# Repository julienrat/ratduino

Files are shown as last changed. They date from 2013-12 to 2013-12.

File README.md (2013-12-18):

Moduluino
======================================

Le moduluino est un arduino basé sur l'ATmega328P, il a l'avantage de concentrer le minimum pour fonctionner. son utilisation est destinée aux modules d'exposition,
le cout estimé est de 13 euros TTC chez seeedstudio.

Les fichiers de production ainsi que la BOM sont disposibles  et sont destinés à etre utilisés avec les services seeedstudio prototyping
http://www.seeedstudio.com/service/index.php?r=site/pcbService&type=pcba

Les fichiers sources sont compatibles EAGLE avec la librairie Open Parts Library  (http://www.seeedstudio.com/wiki/Open_parts_library)
Licence GNU GPL

PCB 

PCB

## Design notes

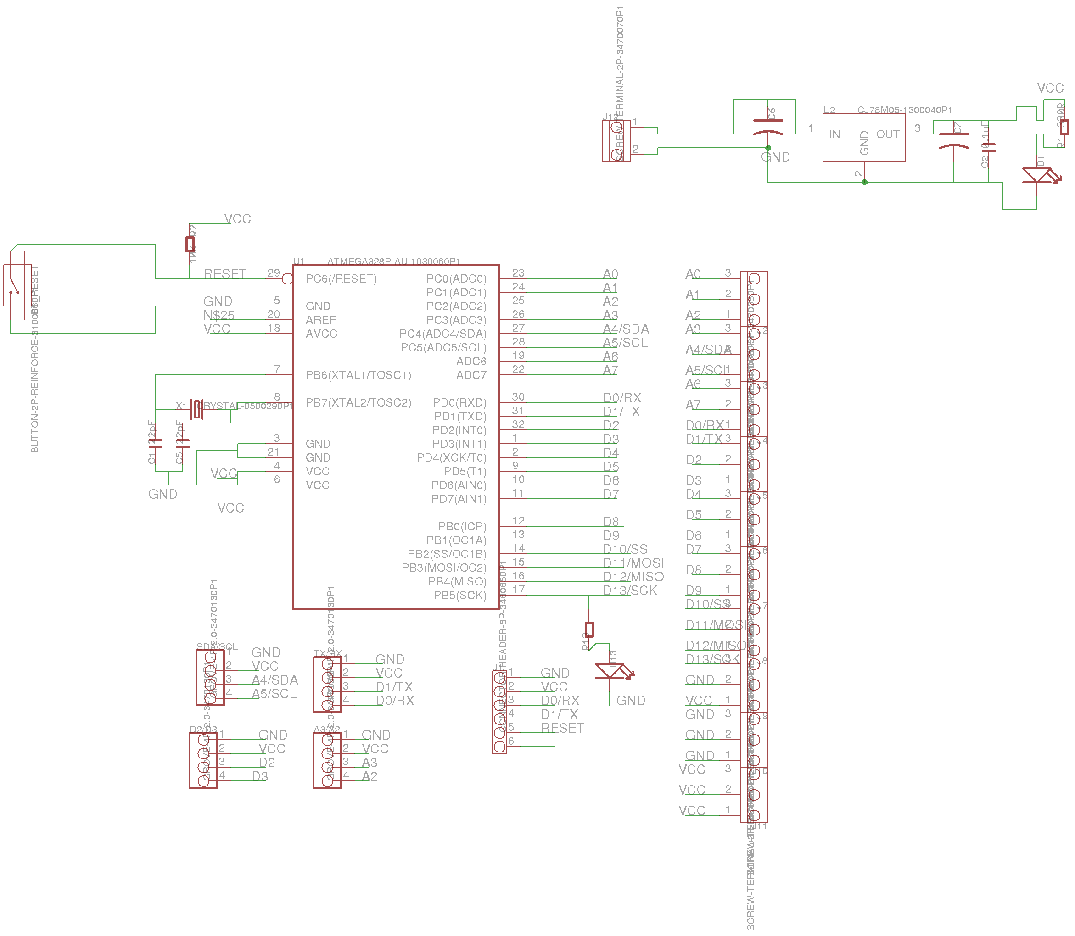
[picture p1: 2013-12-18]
schema.png

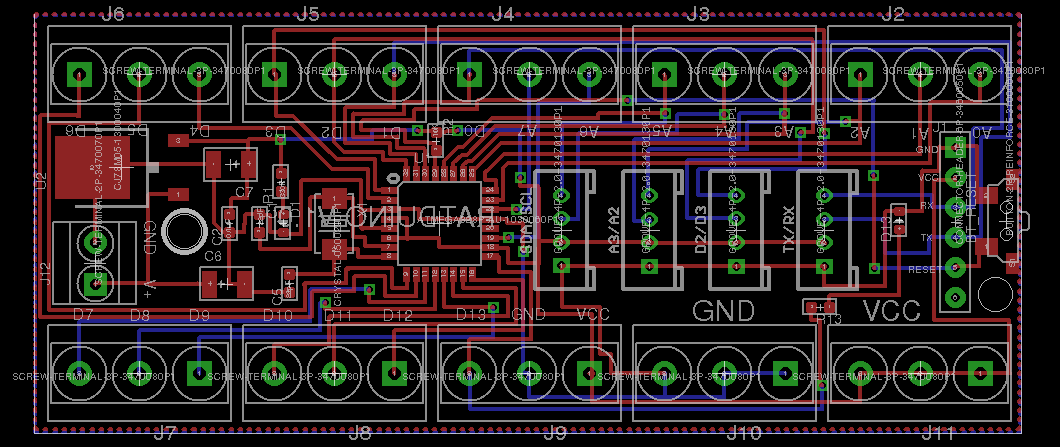
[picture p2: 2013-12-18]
pcb.png

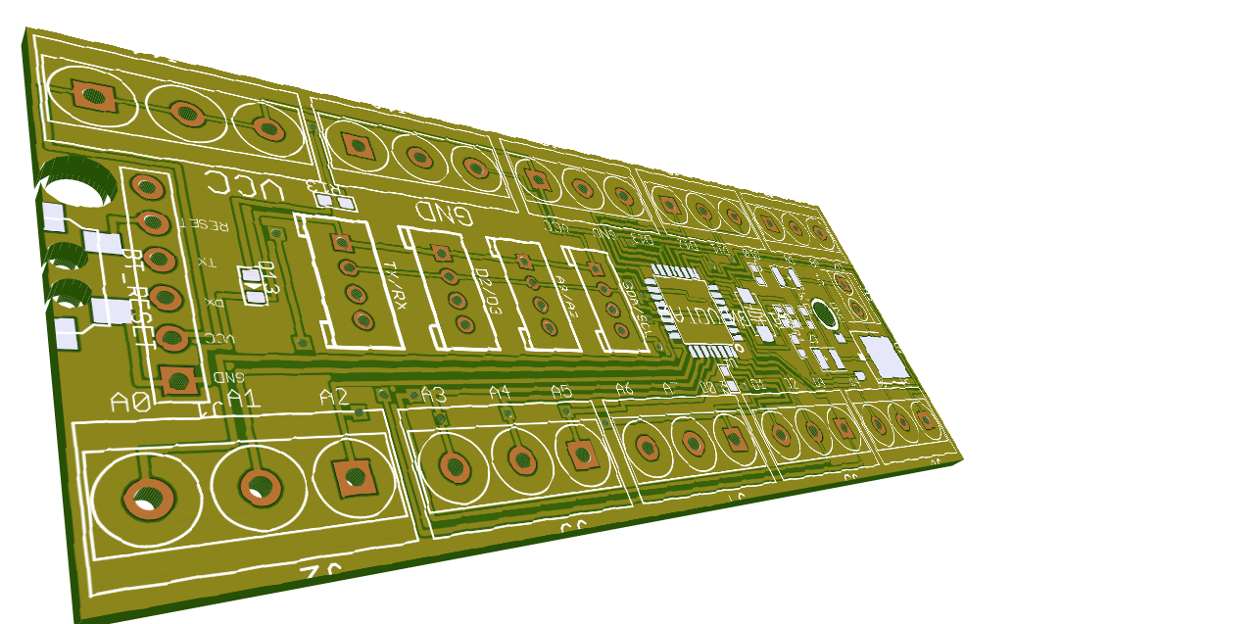
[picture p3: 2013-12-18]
image.png

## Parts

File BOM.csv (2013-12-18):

OPL SKU | Qty. | Parts
3470080P1 | 1 | J2
3470080P1 | 1 | J3
3470080P1 | 1 | J4
3470080P1 | 1 | J5
3470080P1 | 1 | J6
3470080P1 | 1 | J7
3470080P1 | 1 | J8
3470080P1 | 1 | J9
3470080P1 | 1 | J10
3470080P1 | 1 | J11
3470110P1 | 1 | J12
3470130P1 | 1 | TX/RX
3470130P1 | 1 | D2/D3
3470130P1 | 1 | A3/A2
3470130P1 | 1 | SDA/SCL
0500290P1 | 1 | X1
0100620P1 | 1 | C1
0100620P1 | 1 | C5
0010170P1 | 1 | R2
0010430P1 | 1 | R1
0130120P1 | 1 | C6
0130120P1 | 1 | C7
0100020P1 | 1 | C2
0330020P1 | 1 | D1
3460650P1 | 1 | J1
1030060P1 | 1 | U1
1300040P1 | 1 | U2
0330060P1 | 1 | D13
0010430P1 | 1 | R13
3100060P1 | 1 | BT_RESET

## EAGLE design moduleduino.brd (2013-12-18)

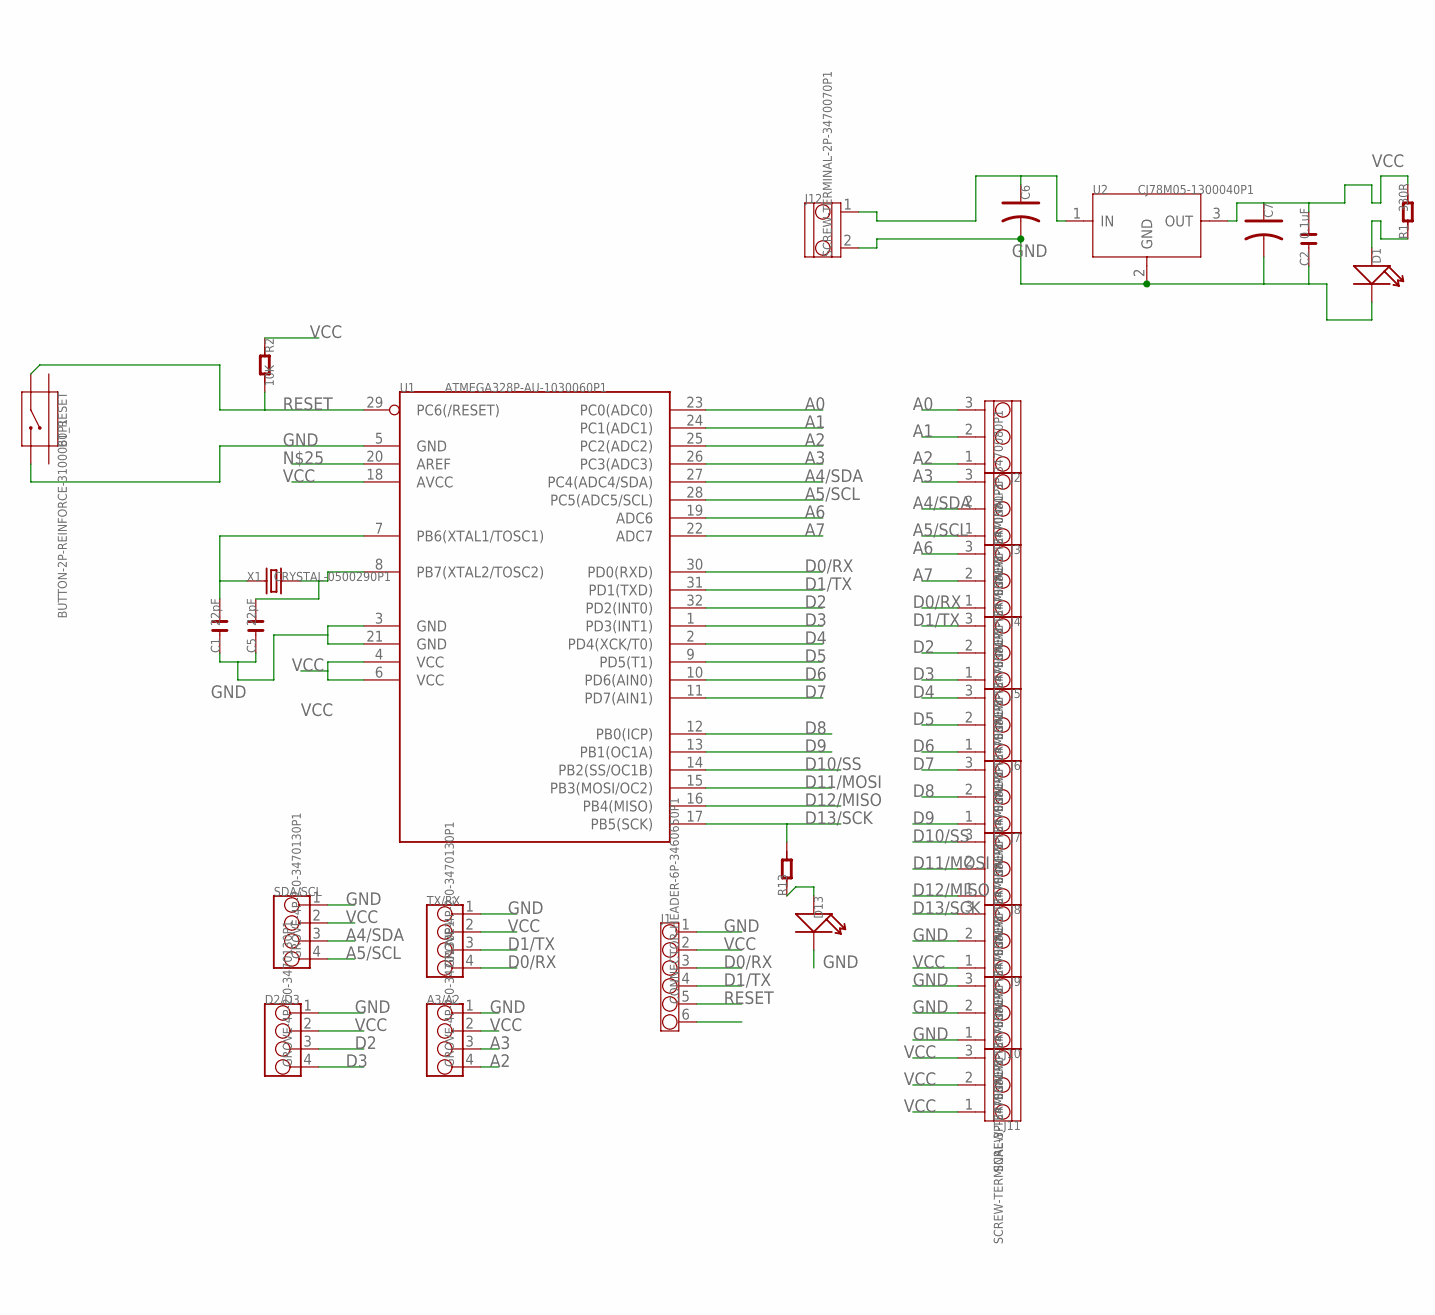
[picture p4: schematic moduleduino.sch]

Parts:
A3/A2: GROVE-4P-2.0-3470130P1; 4P-2.0
BT_RESET: BUTTON-2P-REINFORCE-3100060P1; 4P-SMD-7.0X3.5X3.5H-90D
C1, C5: 22pF; C0603
C2: 0.1uF; C0603
C6, C7: C-POLAR-B; AVX-B
D1, D13: LED; LED0603
D2/D3: GROVE-4P-2.0-3470130P1; 4P-2.0
J1: CONNECTOR-HEADER-6P-3460650P1; 1X6P-2.54-2.54-11.6-3.0-BLACK-MALE
J2, J3, J4, J5, J6, J7, J8, J9, J10, J11: SCREW-TERMINAL-3P-3470080P1; 3P-5.0
J12: SCREW-TERMINAL-2P-3470070P1; 2P-3.5
R1: 330R; R0603
R2: 10K; R0603
R13: R-0603; R0603
SDA/SCL: GROVE-4P-2.0-3470130P1; 4P-2.0
TX/RX: GROVE-4P-2.0-3470130P1; 4P-2.0
U1: ATMEGA328P-AU-1030060P1; TQFP32
U2: CJ78M05-1300040P1; TO252
X1: CRYSTAL-0500290P1; 2P-SMD-5.0X3.2

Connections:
A0: J2.3, U1.23 (PC0(ADC0))
A1: J2.2, U1.24 (PC1(ADC1))
A2: A3/A2.4, J2.1, U1.25 (PC2(ADC2))
A3: A3/A2.3, J3.3, U1.26 (PC3(ADC3))
A4/SDA: J3.2, SDA/SCL.3, U1.27 (PC4(ADC4/SDA))
A5/SCL: J3.1, SDA/SCL.4, U1.28 (PC5(ADC5/SCL))
A6: J4.3, U1.19 (ADC6)
A7: J4.2, U1.22 (ADC7)
D0/RX: J1.3, J4.1, TX/RX.4, U1.30 (PD0(RXD))
D1/TX: J1.4, J5.3, TX/RX.3, U1.31 (PD1(TXD))
D2: D2/D3.3, J5.2, U1.32 (PD2(INT0))
D3: D2/D3.4, J5.1, U1.1 (PD3(INT1))
D4: J6.3, U1.2 (PD4(XCK/T0))
D5: J6.2, U1.9 (PD5(T1))
D6: J6.1, U1.10 (PD6(AIN0))
D7: J7.3, U1.11 (PD7(AIN1))
D8: J7.2, U1.12 (PB0(ICP))
D9: J7.1, U1.13 (PB1(OC1A))
D10/SS: J8.3, U1.14 (PB2(SS/OC1B))
D11/MOSI: J8.2, U1.15 (PB3(MOSI/OC2))
D12/MISO: J8.1, U1.16 (PB4(MISO))
D13/SCK: J9.3, R13.2, U1.17 (PB5(SCK))
GND: A3/A2.1, BT_RESET.2, C1.1, C2.1, C5.1, C6.- (2), C7.- (2), D1.-, D2/D3.1, D13.-, J1.1, J9.2, J10.1, J10.2, J10.3, J12.2, SDA/SCL.1, TX/RX.1, U1.3 (GND), U1.5 (GND), U1.21 (GND), U2.2 (GND)
unnamed: D13.+, R13.1
unnamed: C1.2, U1.7 (PB6(XTAL1/TOSC1)), X1.1
unnamed: C5.2, U1.8 (PB7(XTAL2/TOSC2)), X1.2
unnamed: C6.+ (1), J12.1, U2.1 (IN)
unnamed: D1.+, R1.1
RESET: BT_RESET.1, J1.5, R2.2, U1.29 (PC6(/RESET))
VCC: A3/A2.2, C2.2, C7.+ (1), D2/D3.2, J1.2, J9.1, J11.1, J11.2, J11.3, R1.2, R2.1, SDA/SCL.2, TX/RX.2, U1.4 (VCC), U1.6 (VCC), U1.18 (AVCC), U2.3 (OUT)

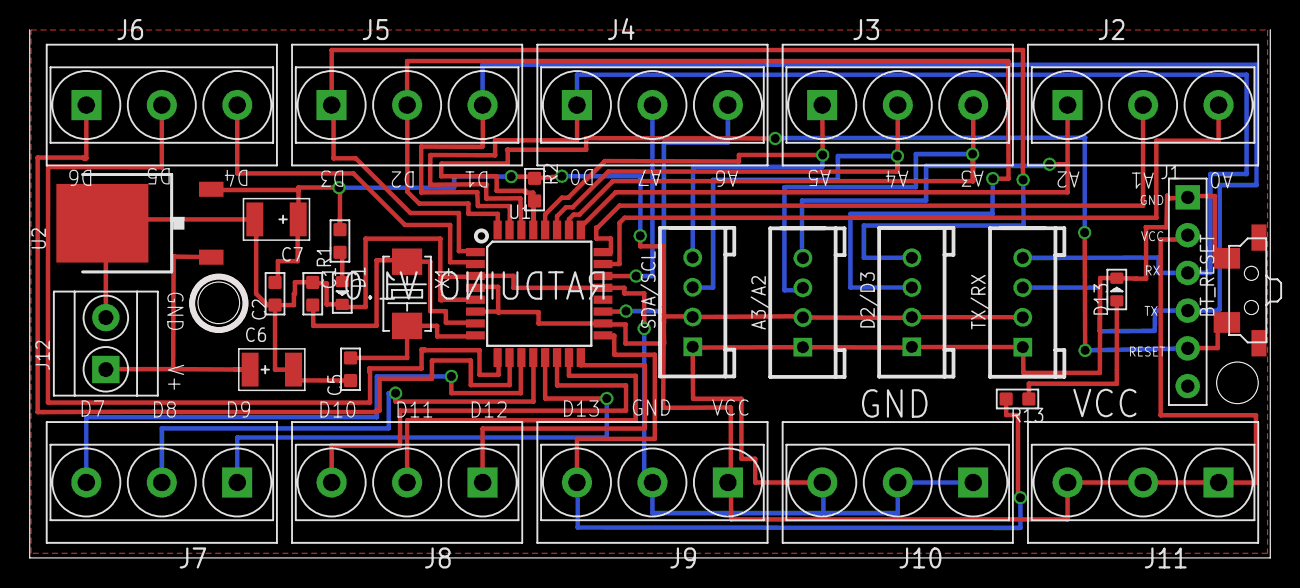
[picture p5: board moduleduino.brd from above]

Board: 4 copper layers, 83.5 x 35.5 mm, 30 parts (0 on the bottom side), 30 nets.

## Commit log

2013-12-18 ajout du projet ratduino
    [BOM.csv, moduleduino.brd, moduleduino.sch]
2014-03-20 + ‘.sparkleshare’
